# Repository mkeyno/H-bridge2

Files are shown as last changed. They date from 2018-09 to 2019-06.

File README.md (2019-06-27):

# H-bridge2
this is H-bridge circuit to operate under 12-24 input voltage, with parallel mosfet and push-pull gate driver
##schematic of last change 
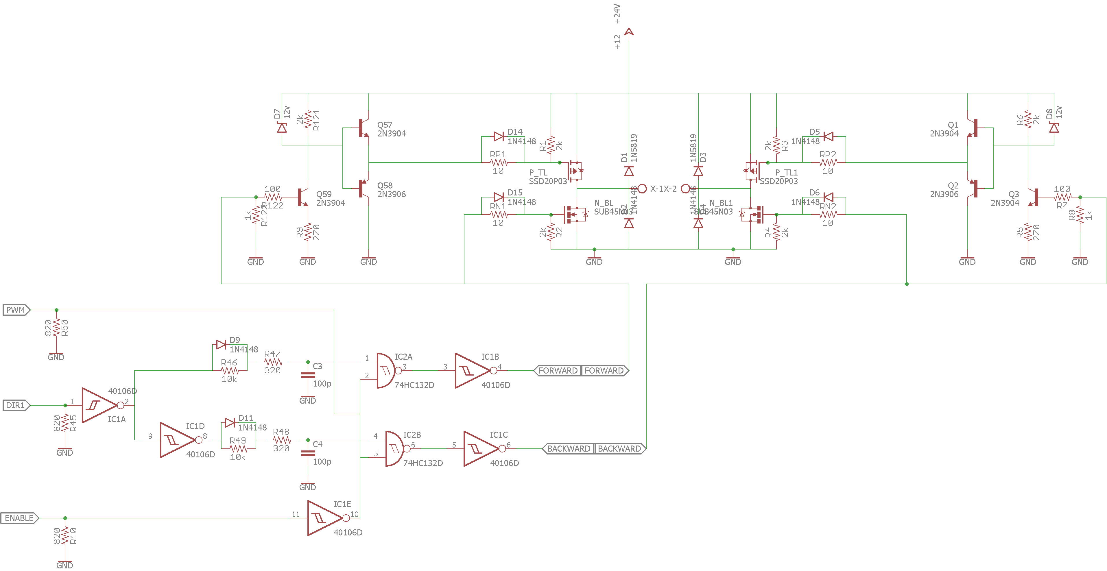
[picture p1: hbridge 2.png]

##PCB
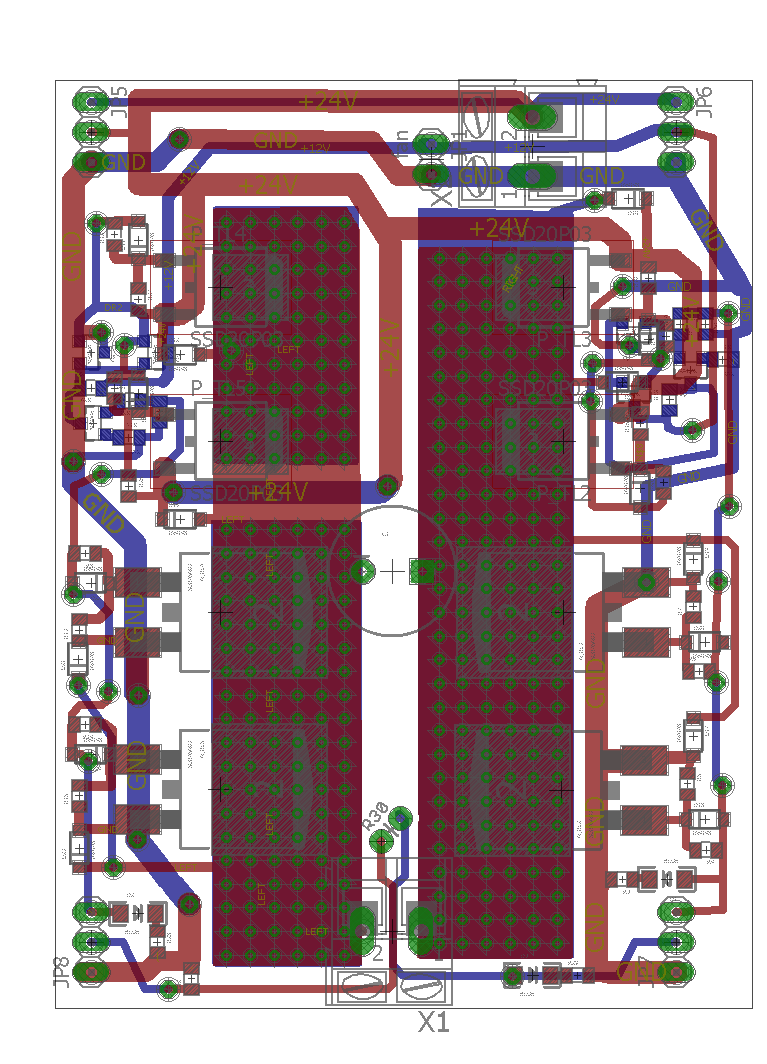
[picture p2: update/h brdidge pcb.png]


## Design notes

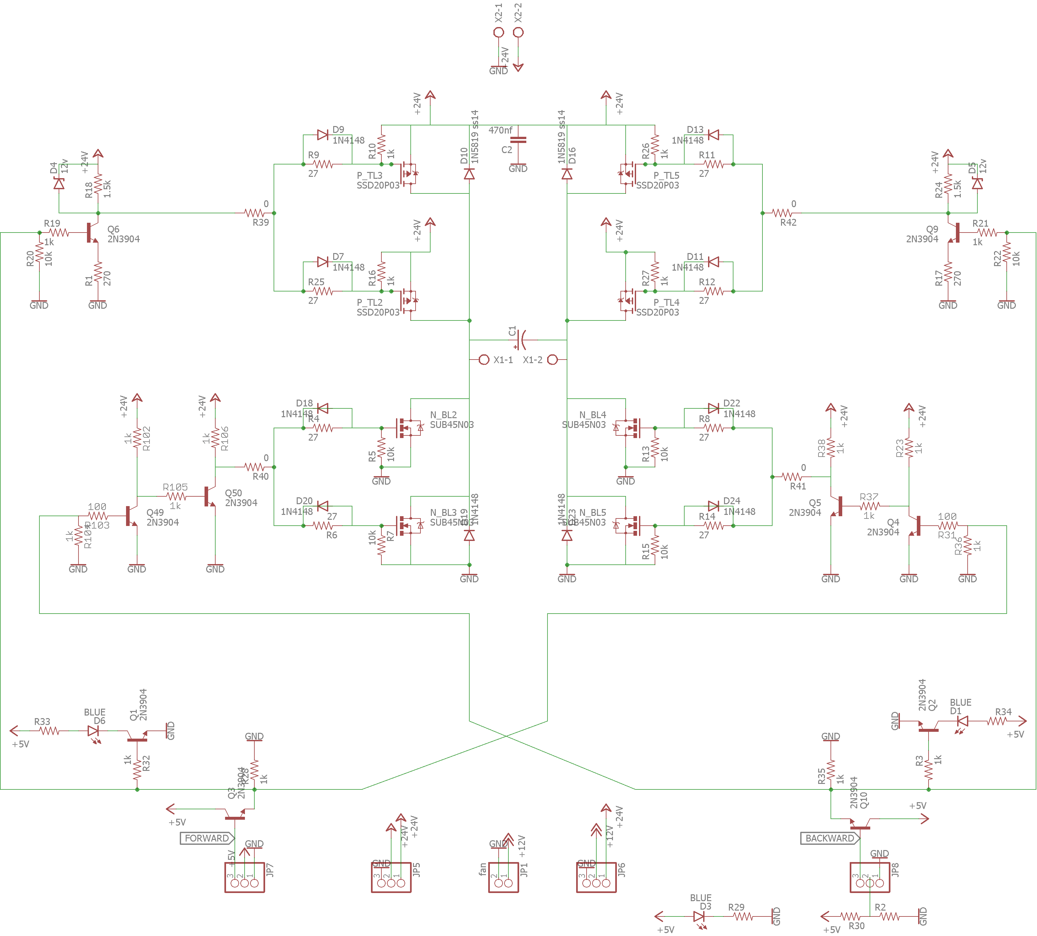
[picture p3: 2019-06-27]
update/h brdidge scb.png

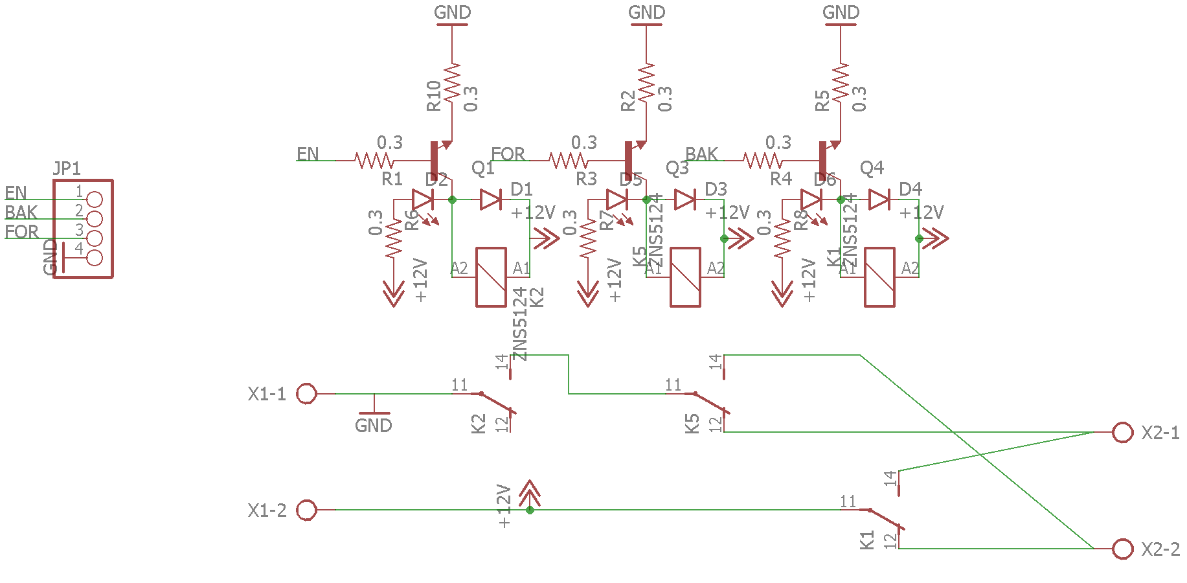
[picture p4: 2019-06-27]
update/relay scb.png

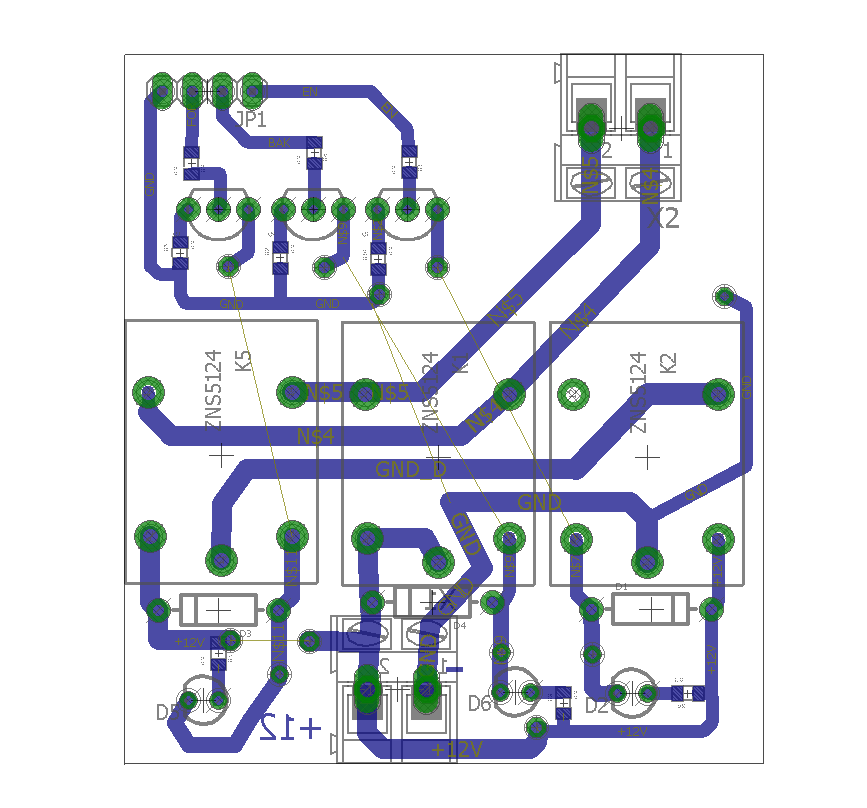
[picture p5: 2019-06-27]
update/relay pcb.png

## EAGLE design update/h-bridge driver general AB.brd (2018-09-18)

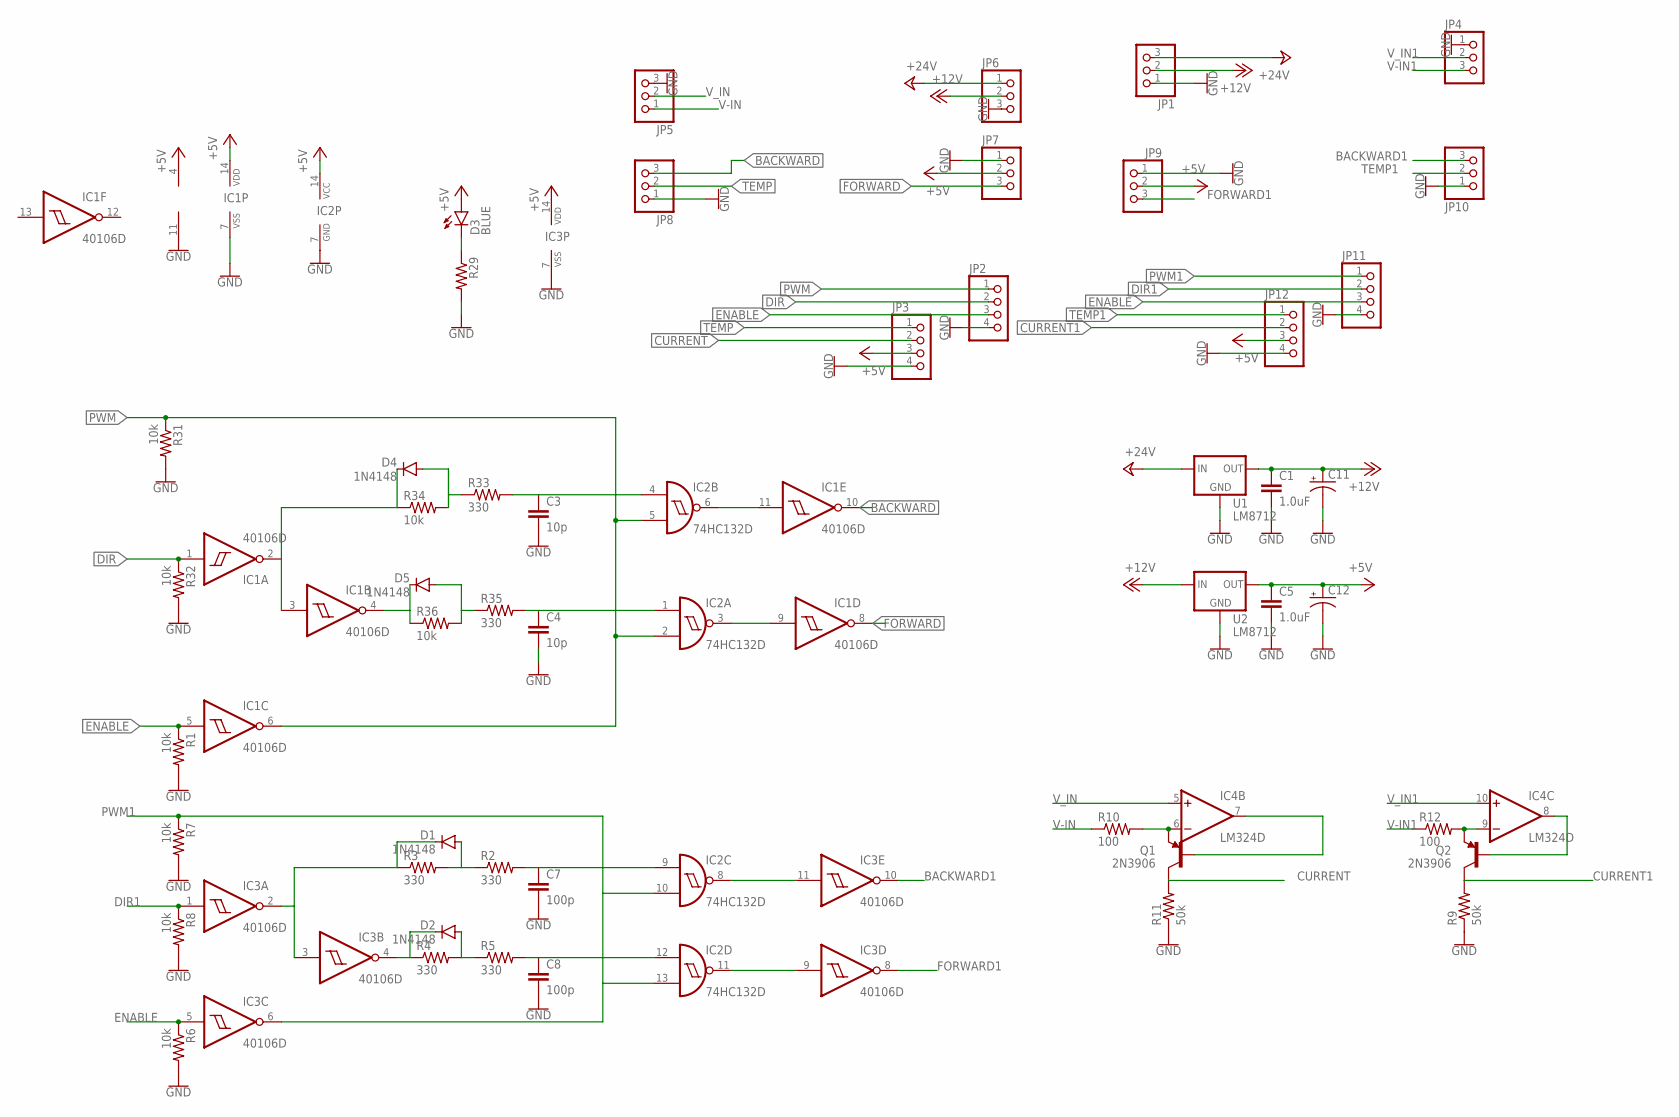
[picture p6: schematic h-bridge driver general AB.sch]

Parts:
C1, C5: 1.0uF; 1206
C3, C4: 10p; 0805-CAP
C7, C8: 100p; 0805-CAP
C11, C12: CAP_POLPTH4; CPOL-RADIAL-1000UF-25V
D1, D2, D4, D5: 1N4148; SOD-123
D3: BLUE; LED-1206
IC1, IC3: 40106D; SO14
IC2: 74HC132D; SO14
IC4: LM324D; SO14
JP1, JP4, JP5, JP6, JP7, JP8, JP9, JP10: PINHD-1X3; 1X03
JP2, JP3, JP11, JP12: PINHD-1X4; 1X04
Q1, Q2: 2N3906; SOT23-3
R1, R6, R7, R8, R31, R32, R34, R36: 10k; 0805
R2, R3, R4, R5, R33, R35: 330; 0805
R9, R11: 50k; 0805
R10, R12: 100; 0805
R29: 0.3OHM-1/8W-1%(0805); 0805
U1, U2: LM8712; 78XXL

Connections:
+5V: C5.1, C12.+, D3.A, IC1.14 (VDD), IC2.14 (VCC), IC3.14 (VDD), IC4.4 (V+), JP3.3, JP7.2, JP9.2, JP12.3, U2.OUT
+12V: C1.1, C11.+, JP1.2, JP6.2, U1.OUT, U2.IN
+24V: JP1.3, JP6.1, U1.IN
BACKWARD: IC1.10 (O), JP8.3
BACKWARD1: IC3.10 (O), JP10.3
CURRENT: JP3.2, Q1.3 (C), R11.2
CURRENT1: JP12.2, Q2.3 (C), R9.2
DIR: IC1.1 (I), JP2.2, R32.1
DIR1: IC3.1 (I), JP11.2, R8.1
ENABLE: IC1.5 (I), IC3.5 (I), JP2.3, JP11.3, R1.1, R6.1
FORWARD: IC1.8 (O), JP7.3
FORWARD1: IC3.8 (O), JP9.3
GND: C1.2, C3.2, C4.2, C5.2, C7.2, C8.2, C11.-, C12.-, IC1.7 (VSS), IC2.7 (GND), IC3.7 (VSS), IC4.11 (V-), JP1.1, JP2.4, JP3.4, JP4.1, JP5.3, JP6.3, JP7.1, JP8.1, JP9.1, JP10.1, JP11.4, JP12.4, R1.2, R6.2, R7.2, R8.2, R9.1, R11.1, R29.2, R31.2, R32.2, U1.GND, U2.GND
unnamed: IC1.11 (I), IC2.6 (O)
unnamed: IC1.9 (I), IC2.3 (O)
unnamed: IC2.8 (O), IC3.11 (I)
unnamed: IC2.11 (O), IC3.9 (I)
unnamed: C7.1, IC2.9 (I0), R2.2
unnamed: D3.C, R29.1
unnamed: D1.A, R2.1, R3.2
unnamed: D1.C, IC3.2 (O), IC3.3 (I), R3.1
unnamed: IC4.6 (-IN), Q1.2 (E), R10.2
unnamed: D2.C, IC3.4 (O), R4.1
unnamed: D2.A, R4.2, R5.1
unnamed: C8.1, IC2.12 (I0), R5.2
unnamed: IC4.7 (OUT), Q1.1 (B)
unnamed: IC4.9 (-IN), Q2.2 (E), R12.2
unnamed: IC4.8 (OUT), Q2.1 (B)
unnamed: D4.C, IC1.2 (O), IC1.3 (I), R34.1
unnamed: D4.A, R33.1, R34.2
unnamed: C3.1, IC2.4 (I0), R33.2
unnamed: C4.1, IC2.1 (I0), R35.2
unnamed: D5.A, R35.1, R36.2
unnamed: D5.C, IC1.4 (O), R36.1
PWM: IC1.6 (O), IC2.2 (I1), IC2.5 (I1), JP2.1, R31.1
PWM1: IC2.10 (I1), IC2.13 (I1), IC3.6 (O), JP11.1, R7.1
TEMP: JP3.1, JP8.2
TEMP1: JP10.2, JP12.1
V-IN: JP5.1, R10.1
V-IN1: JP4.3, R12.1
V_IN: IC4.5 (+IN), JP5.2
V_IN1: IC4.10 (+IN), JP4.2

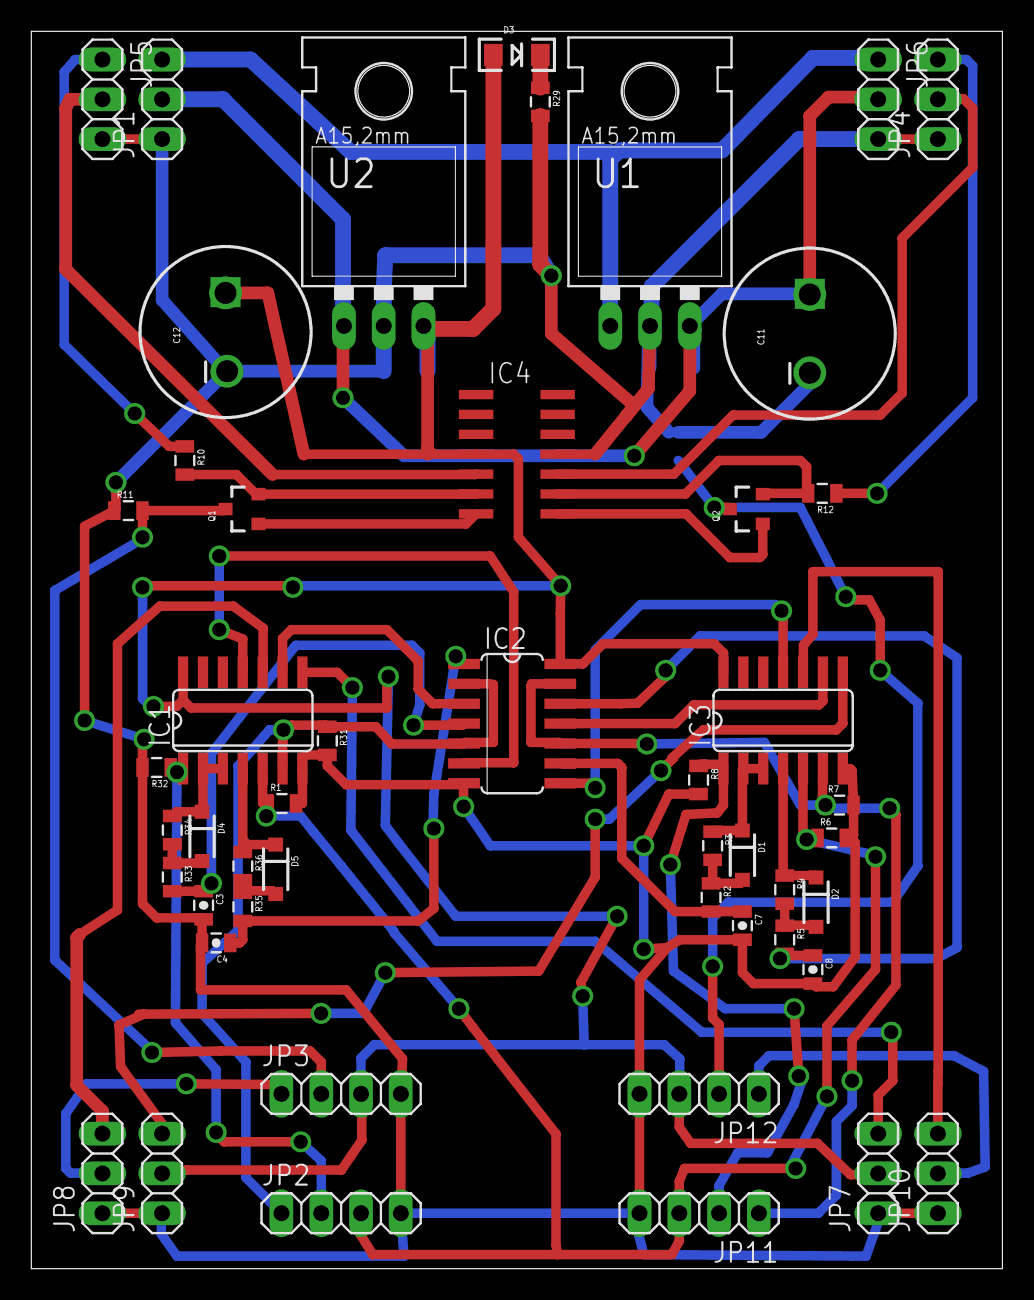
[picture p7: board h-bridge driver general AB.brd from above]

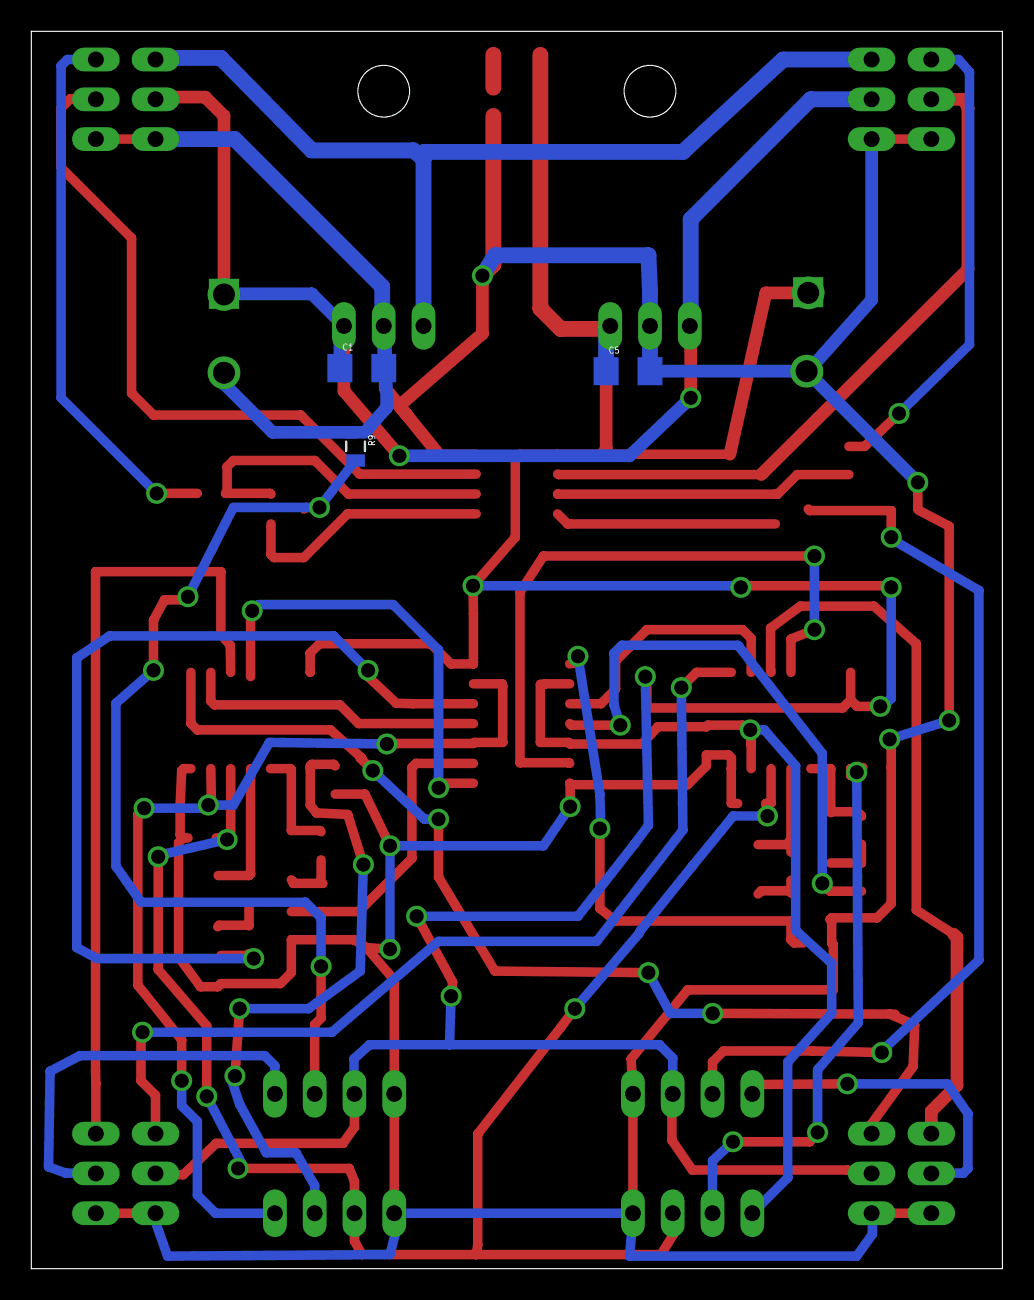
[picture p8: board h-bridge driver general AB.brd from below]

Board: 2 copper layers, 62.0 x 79.0 mm, 52 parts (3 on the bottom side), 42 nets.

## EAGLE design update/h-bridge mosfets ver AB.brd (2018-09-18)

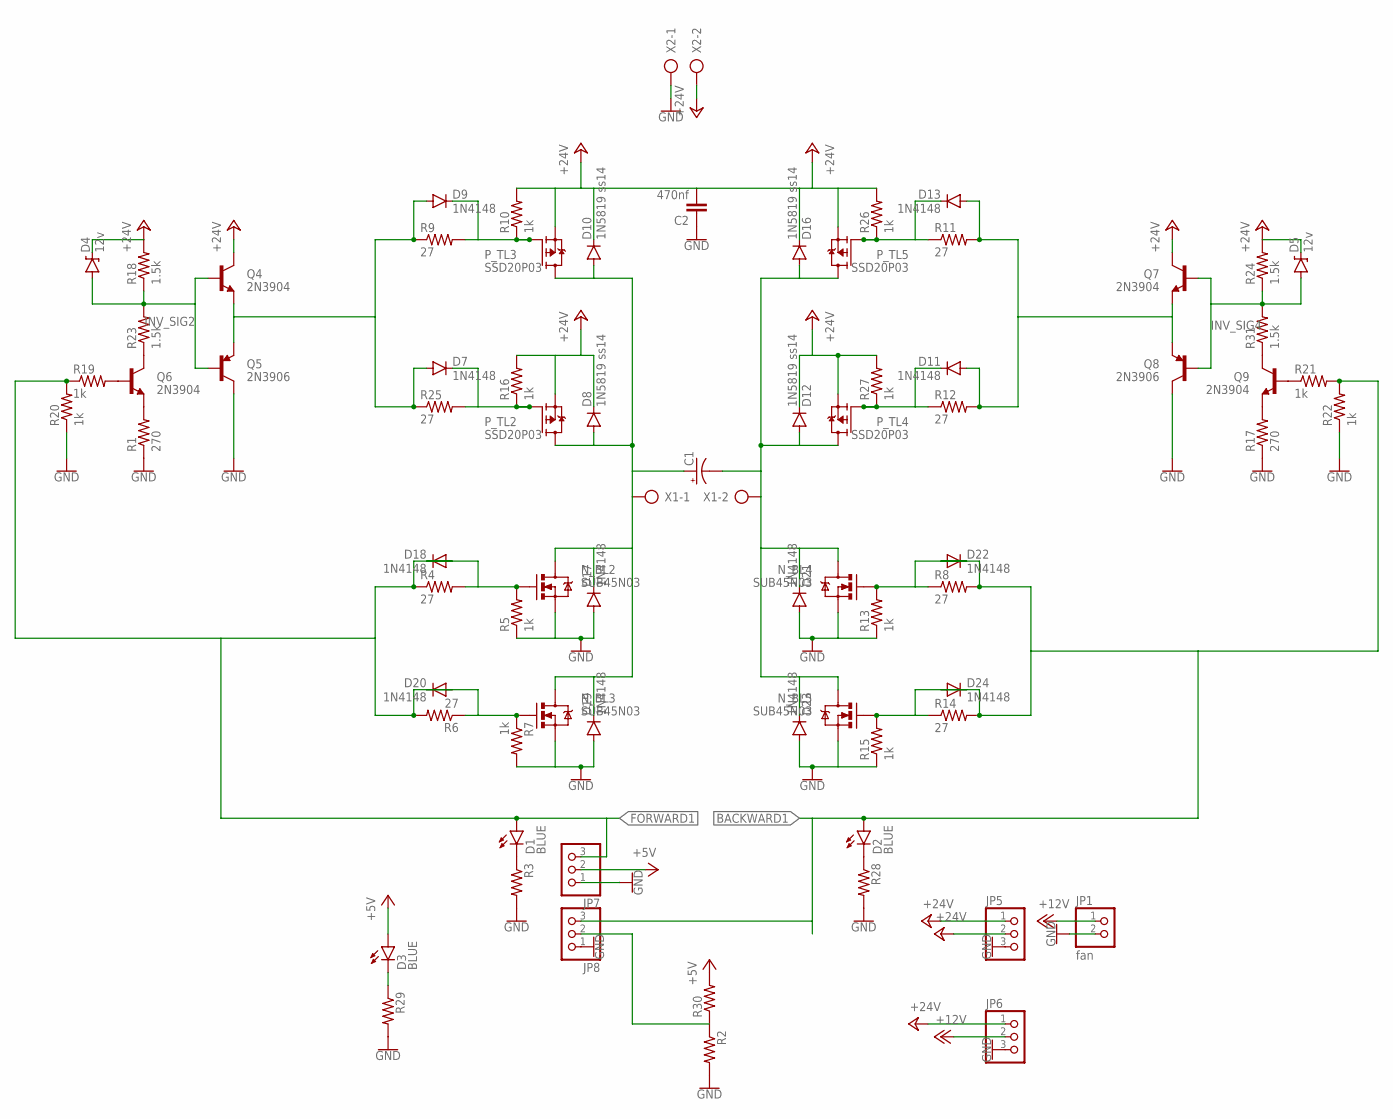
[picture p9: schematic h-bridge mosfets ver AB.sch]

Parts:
C1: 1000UF-25V(PTH); CPOL-RADIAL-1000UF-25V
C2: 470nf; 1206
D1, D2, D3: BLUE; LED-1206
D4, D5: 12v; SMB-DIODE
D7, D9, D11, D13, D17, D18, D19, D20, D21, D22, D23, D24: 1N4148; SOD-123
D8, D10, D12, D16: 1N5819 ss14; SOD-123
JP1: fan; 1X02
JP5, JP6, JP7, JP8: PINHD-1X3; 1X03
N_BL2, N_BL3, N_BL4, N_BL5: SUB45N03; TO-263/D2PAK
P_TL2, P_TL3, P_TL4, P_TL5: SSD20P03; TO252
Q4, Q6, Q7, Q9: 2N3904; SOT23-3
Q5, Q8: 2N3906; SOT23-3
R1, R17: 270; 0805
R2, R3, R28, R29: 0.3OHM-1/8W-1%(0805); 0805
R4, R6, R8, R9, R11, R12, R14, R25: 27; 0805
R5, R7, R10, R13, R15, R16, R19, R20, R21, R22, R26, R27: 1k; 0805
R18, R23, R24, R31: 1.5k; 0805
R30: RESISTORPTH-1/4W-VERT-KIT; AXIAL-0.1EZ
X1, X2: AK300/2

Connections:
+5V: D3.A, JP7.2, R30.P$2 (2)
+12V: JP1.1, JP6.2
+24V: C2.2, D4.C, D5.C, D8.C, D10.C, D12.C, D16.C, JP5.1, JP5.2, JP6.1, P_TL2.2 (S), P_TL3.2 (S), P_TL4.2 (S), P_TL5.2 (S), Q4.3 (C), Q7.3 (C), R10.2, R16.2, R18.2, R24.2, R26.2, R27.2, X2.2
BACKWARD1: D2.A, D22.A, D24.A, JP8.3, R8.2, R14.2, R21.2, R22.2
DR2: D11.A, D13.A, Q7.2 (E), Q8.2 (E), R11.2, R12.2
FORWARD1: D1.A, D18.A, D20.A, JP7.3, R4.1, R6.2, R19.1, R20.2
GND: C2.1, D17.A, D19.A, D21.A, D23.A, JP1.2, JP5.3, JP6.3, JP7.1, JP8.1, N_BL2.3 (S), N_BL3.3 (S), N_BL4.3 (S), N_BL5.3 (S), Q5.3 (C), Q8.3 (C), R1.1, R2.2, R3.2, R5.1, R7.2, R13.1, R15.1, R17.1, R20.1, R22.1, R28.2, R29.2, X2.1
INV_SIG2: D4.A, Q4.1 (B), Q5.1 (B), R18.1, R23.2
INV_SIG4: D5.A, Q7.1 (B), Q8.1 (B), R24.1, R31.2
LEFT: C1.-, D12.A, D16.A, D21.C, D23.C, N_BL4.2 (D), N_BL5.2 (D), P_TL4.3 (D), P_TL5.3 (D), X1.2
unnamed: Q6.2 (E), R1.2
unnamed: Q6.1 (B), R19.2
unnamed: Q9.1 (B), R21.1
unnamed: Q9.2 (E), R17.2
unnamed: D1.C, R3.1
unnamed: D2.C, R28.1
unnamed: D3.C, R29.1
unnamed: D7.C, P_TL2.1 (G), R16.1, R25.2
unnamed: D20.C, N_BL3.1 (G), R6.1, R7.1
unnamed: JP8.2, R2.1, R30.P$1 (1)
unnamed: D9.C, P_TL3.1 (G), R9.2, R10.1
unnamed: D22.C, N_BL4.1 (G), R8.1, R13.2
unnamed: Q6.3 (C), R23.1
unnamed: D11.C, P_TL4.1 (G), R12.1, R27.1
unnamed: Q9.3 (C), R31.1
unnamed: D13.C, P_TL5.1 (G), R11.1, R26.1
unnamed: D7.A, D9.A, Q4.2 (E), Q5.2 (E), R9.1, R25.1
unnamed: D18.C, N_BL2.1 (G), R4.2, R5.2
unnamed: D24.C, N_BL5.1 (G), R14.1, R15.2
RIGHT: C1.+, D8.A, D10.A, D17.C, D19.C, N_BL2.2 (D), N_BL3.2 (D), P_TL2.3 (D), P_TL3.3 (D), X1.1

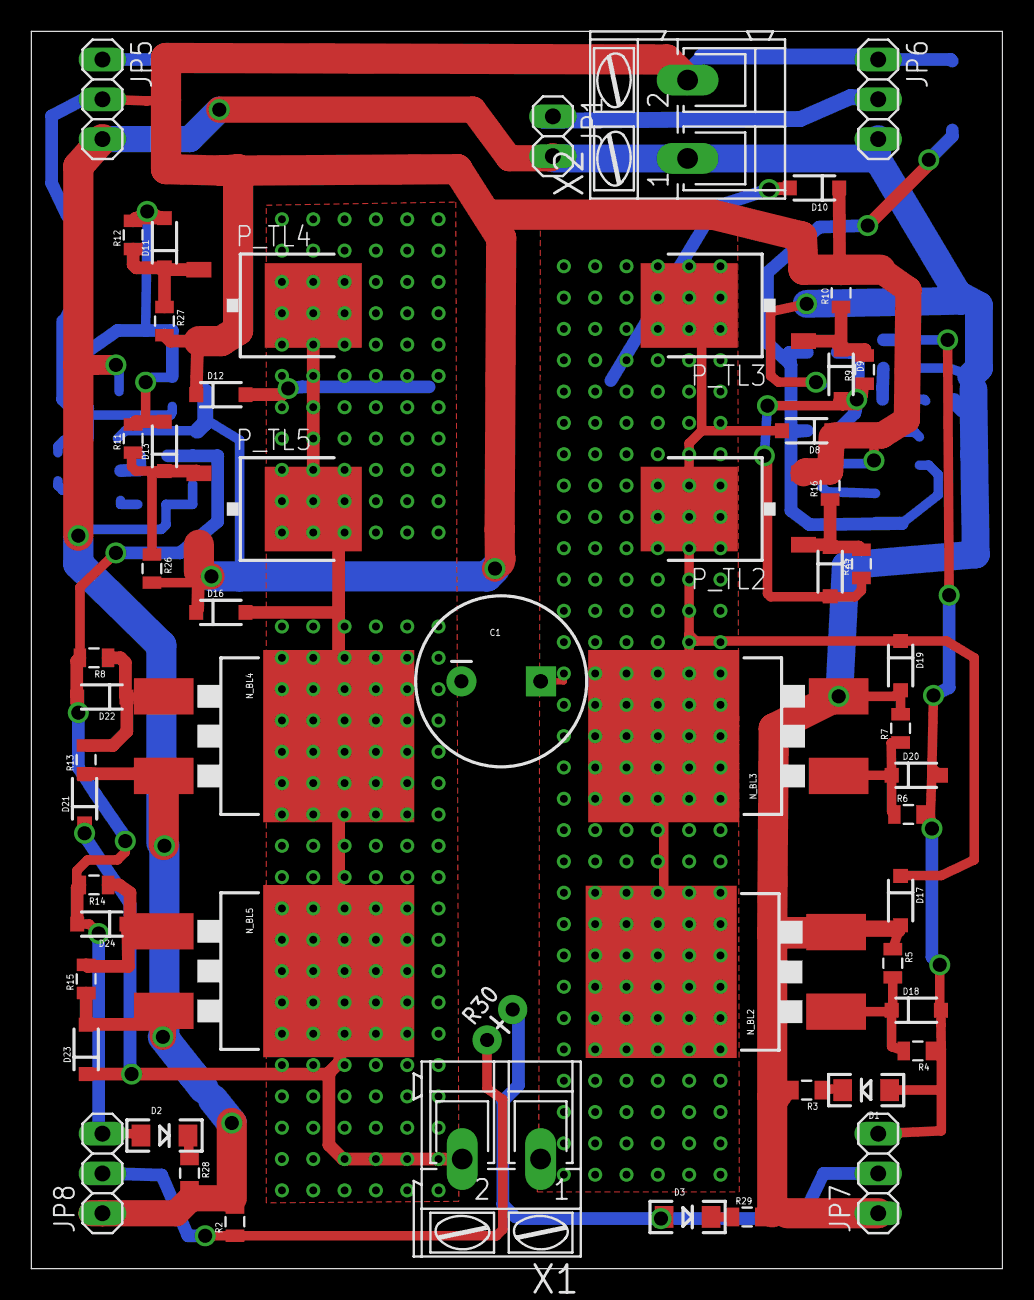
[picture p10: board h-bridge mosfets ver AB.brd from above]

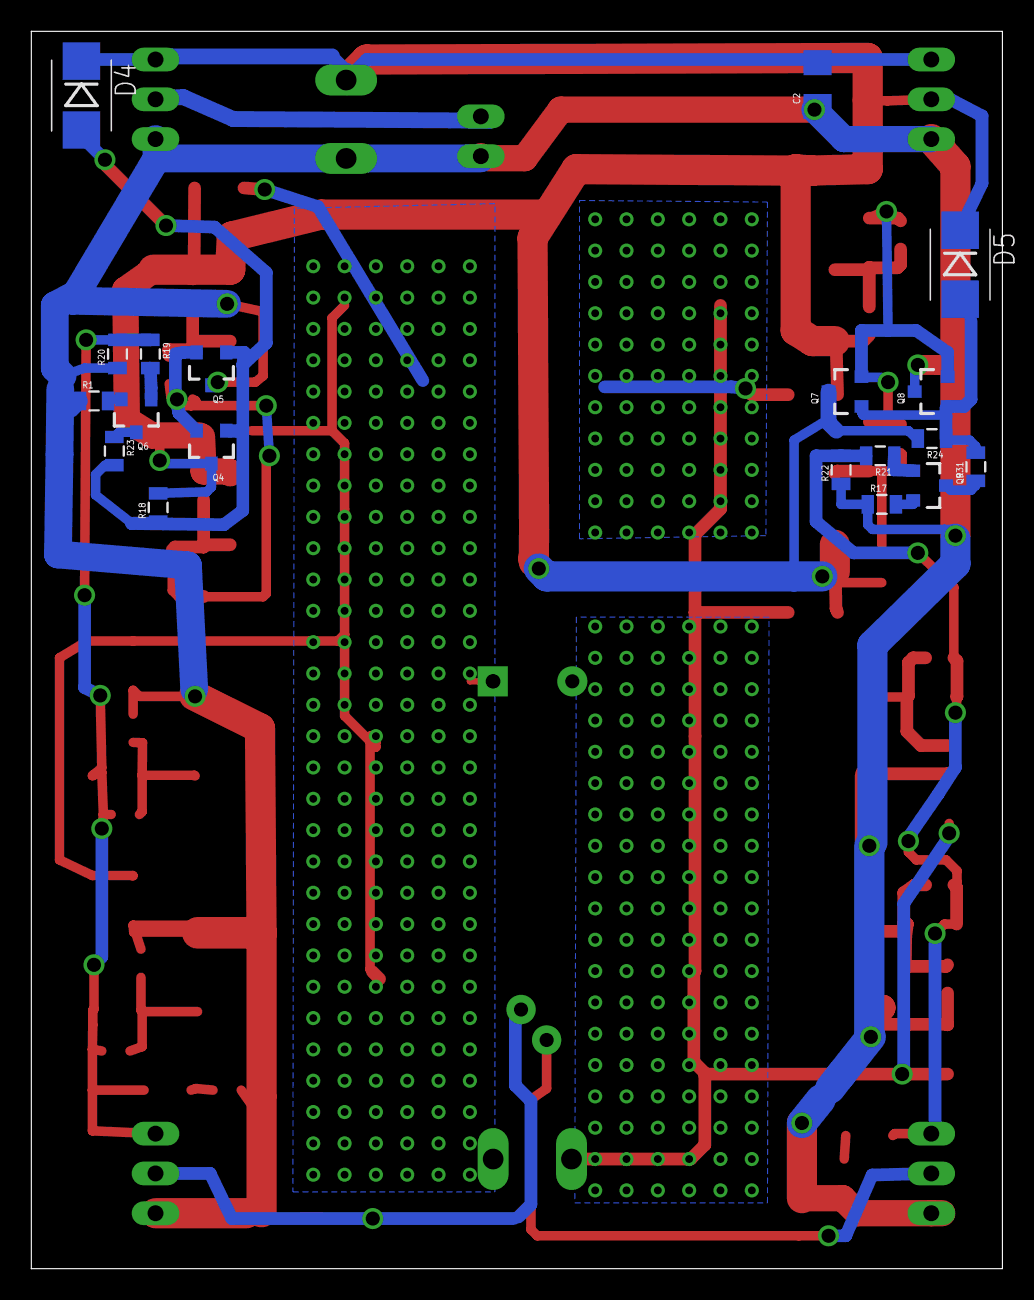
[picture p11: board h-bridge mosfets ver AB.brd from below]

Board: 2 copper layers, 62.0 x 79.0 mm, 75 parts (19 on the bottom side), 30 nets.

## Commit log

2018-09-13 schematic of H-bridge with parallel mosfet and push-pull gate driver
    [h-bridge v2.sch]
2018-09-13 12v line remove and DIODE-ZENER 12v added
    [h-bridge v3.sch]
2018-09-18 driver pcb
    [h-bridge mosfets ver 4.sch, h-bridge mosfets ver AB.brd]
2018-09-18 power mosfet board
    [h-bridge mosfets ver AB.sch]
2018-09-18 NAND gate driver
    [h-bridge driver general AB.brd, h-bridge driver general AB.sch]
2019-06-27 updated circuit

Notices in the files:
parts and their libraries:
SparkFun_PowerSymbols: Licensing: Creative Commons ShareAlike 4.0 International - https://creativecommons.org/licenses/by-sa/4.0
